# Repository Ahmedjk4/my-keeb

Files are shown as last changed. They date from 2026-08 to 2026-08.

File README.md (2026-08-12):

# my-keeb

A custom 60% mechanical keyboard that I designed from scratch, sponsored by Hack Club ❤️
### Each step is also found in commits with description

## Planning the Keyboard

I started by deciding on the layout and then decided what I wanted to include. I decided to include rgb leds, a rotary encoder, and a buzzer.
Took me about 15 minutes or less

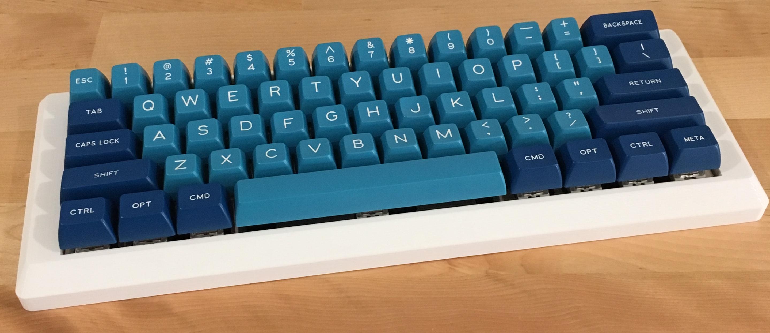
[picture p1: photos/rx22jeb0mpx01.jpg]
Planning


## Designing the PCB

I designed the schematic and PCB in KiCad. This was one of the hardest parts because it was my first time designing a PCB.
This holy step took more than 12 hours

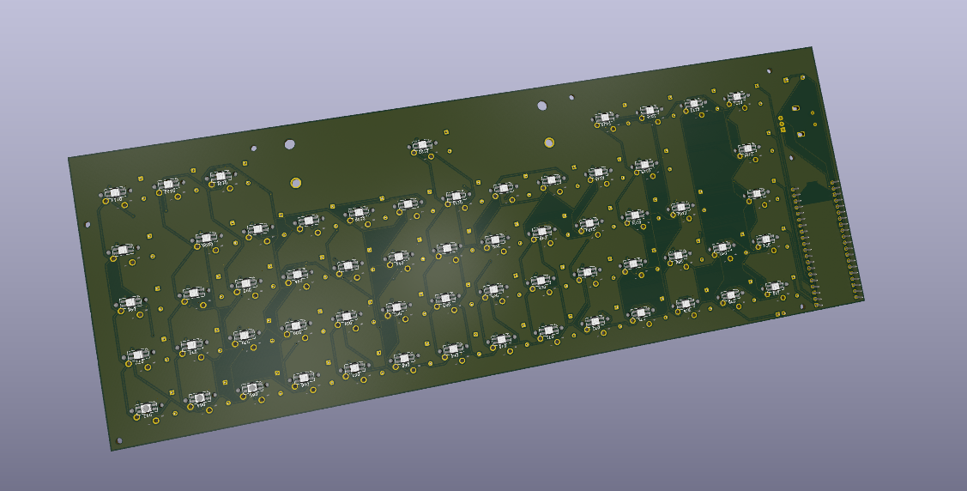
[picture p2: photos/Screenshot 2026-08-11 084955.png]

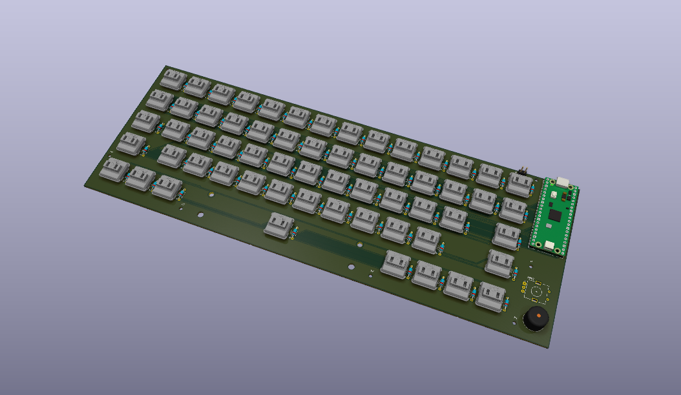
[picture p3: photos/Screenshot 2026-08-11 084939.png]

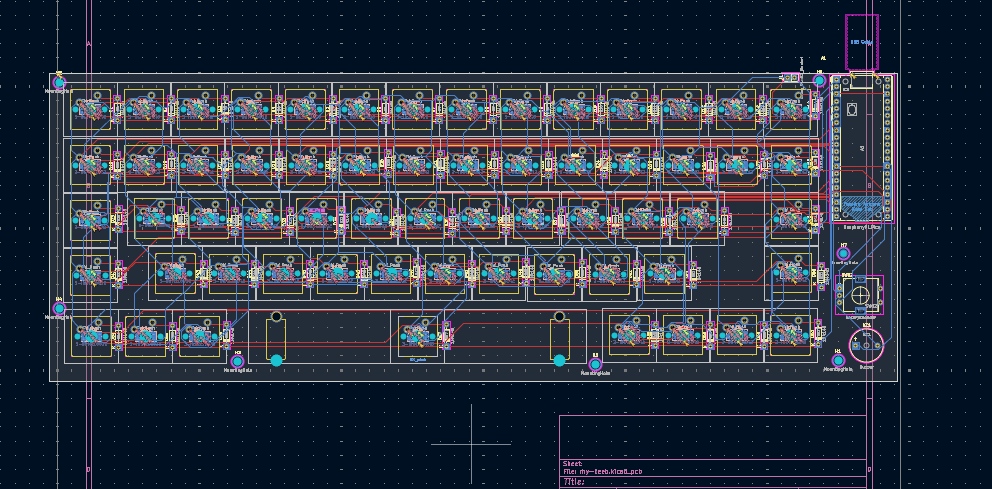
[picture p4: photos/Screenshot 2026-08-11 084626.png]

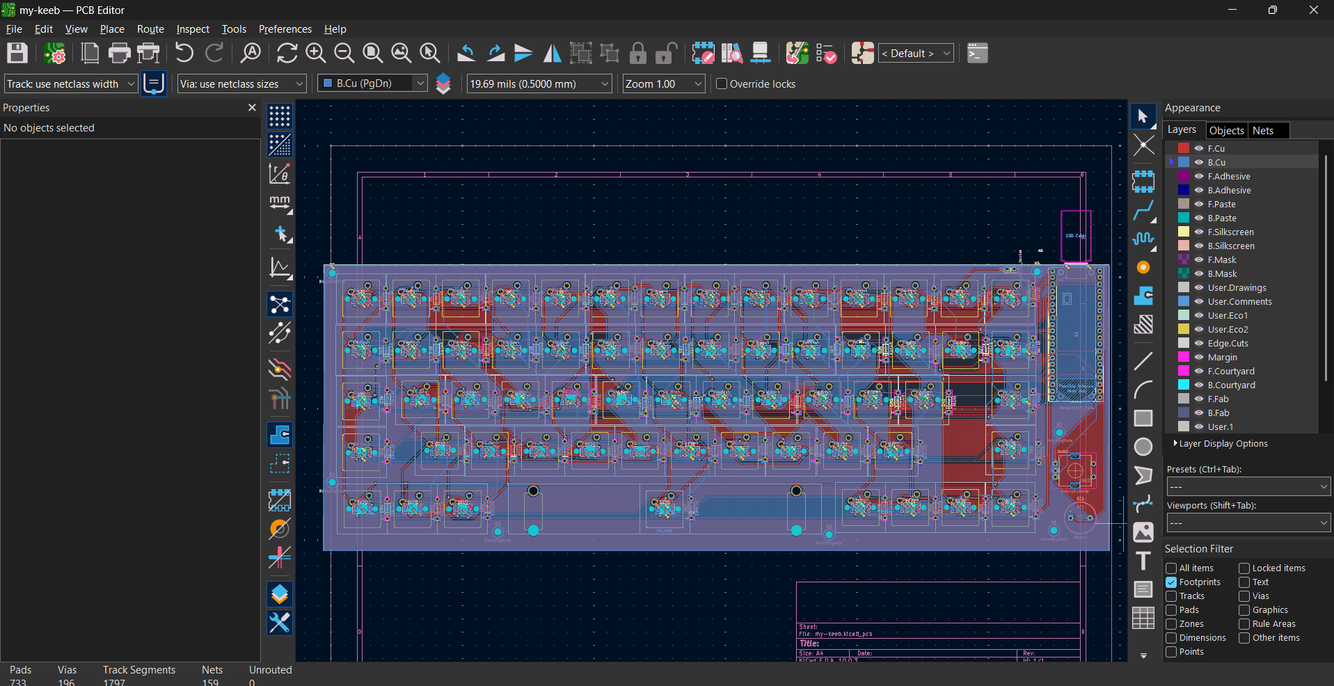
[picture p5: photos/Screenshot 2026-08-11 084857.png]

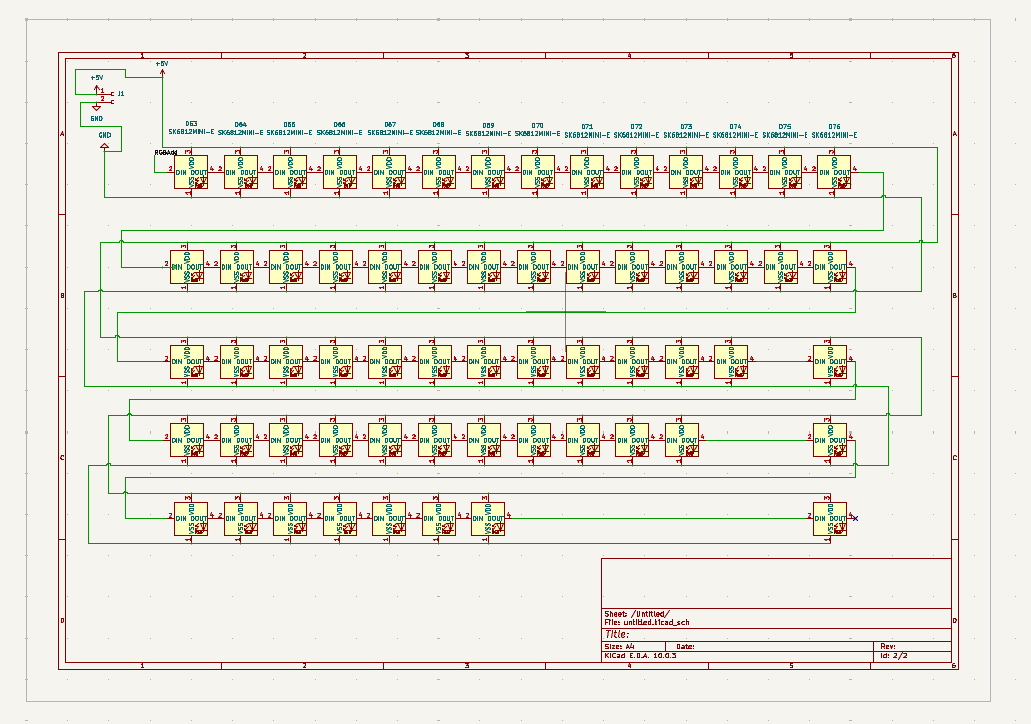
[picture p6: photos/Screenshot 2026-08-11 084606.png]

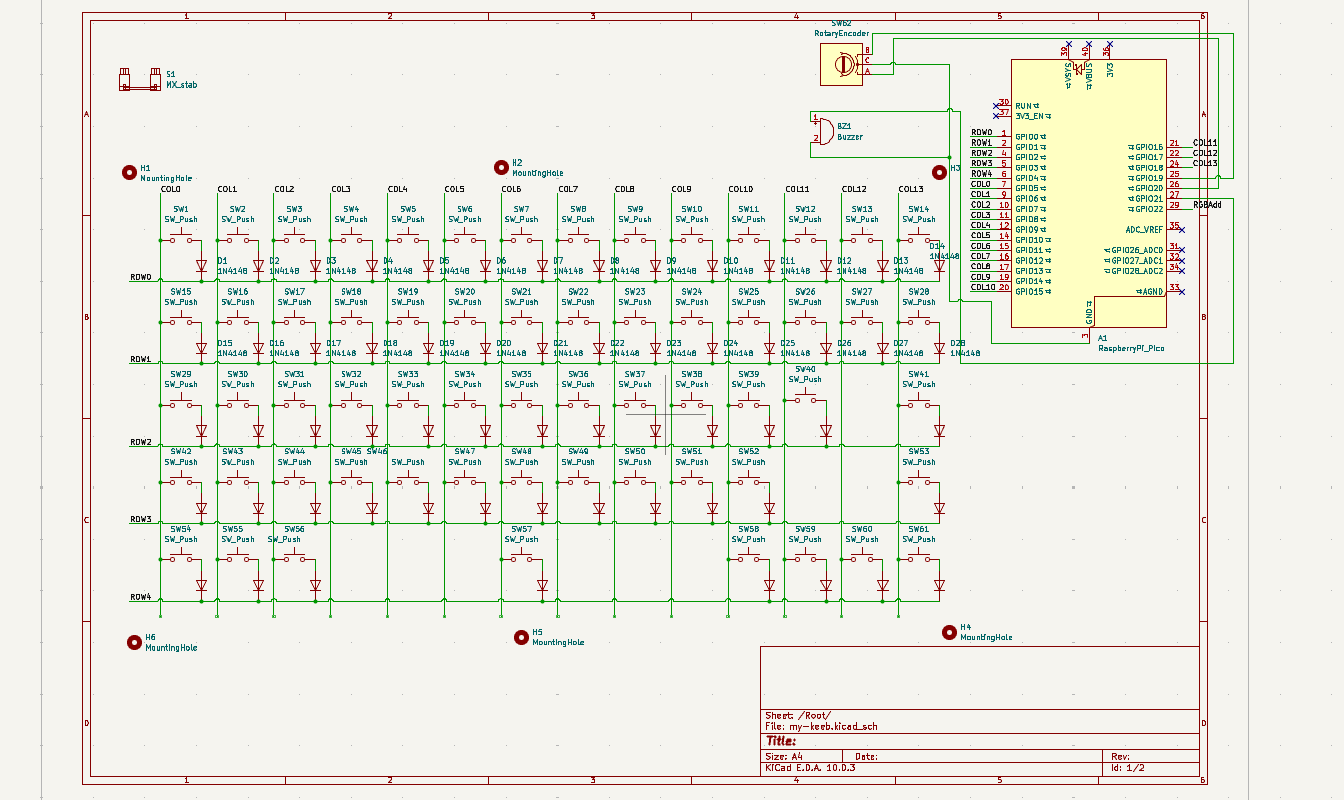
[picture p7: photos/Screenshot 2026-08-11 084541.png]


## Designing the Case

After finishing the PCB, I designed a 3D-printed case around it using Onshape.
Took me 6 hours because of the constrains tools always mess up when I try to move a sketch rectangle to fit the key.
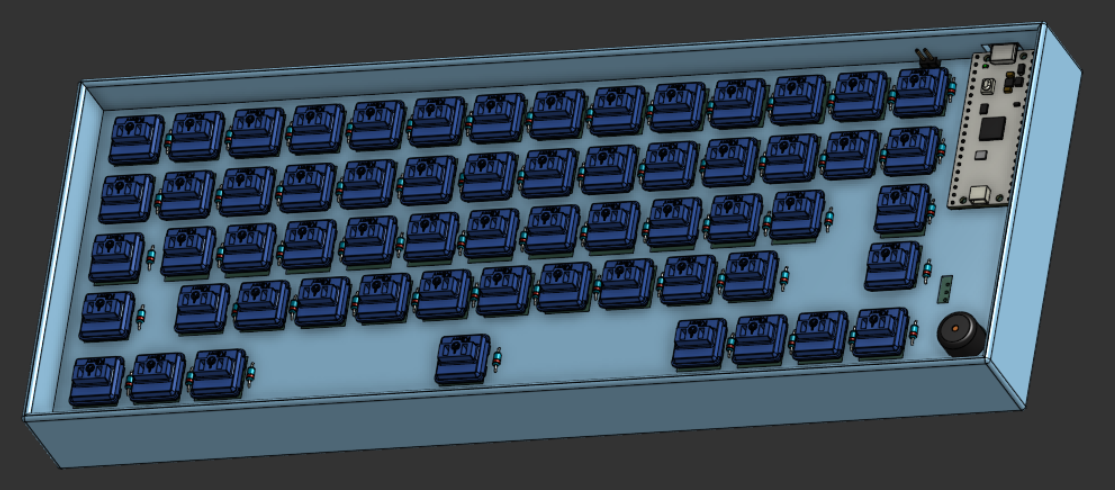
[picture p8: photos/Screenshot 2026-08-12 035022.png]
Case


## Writing the Firmware

Finally, I wrote the keyboard firmware using RMK firmware ( didn't write it I actually edited a .toml file ) and built it on github actions, on my repo https://github.com/Ahmedjk4/custom-keyboard-firmware/

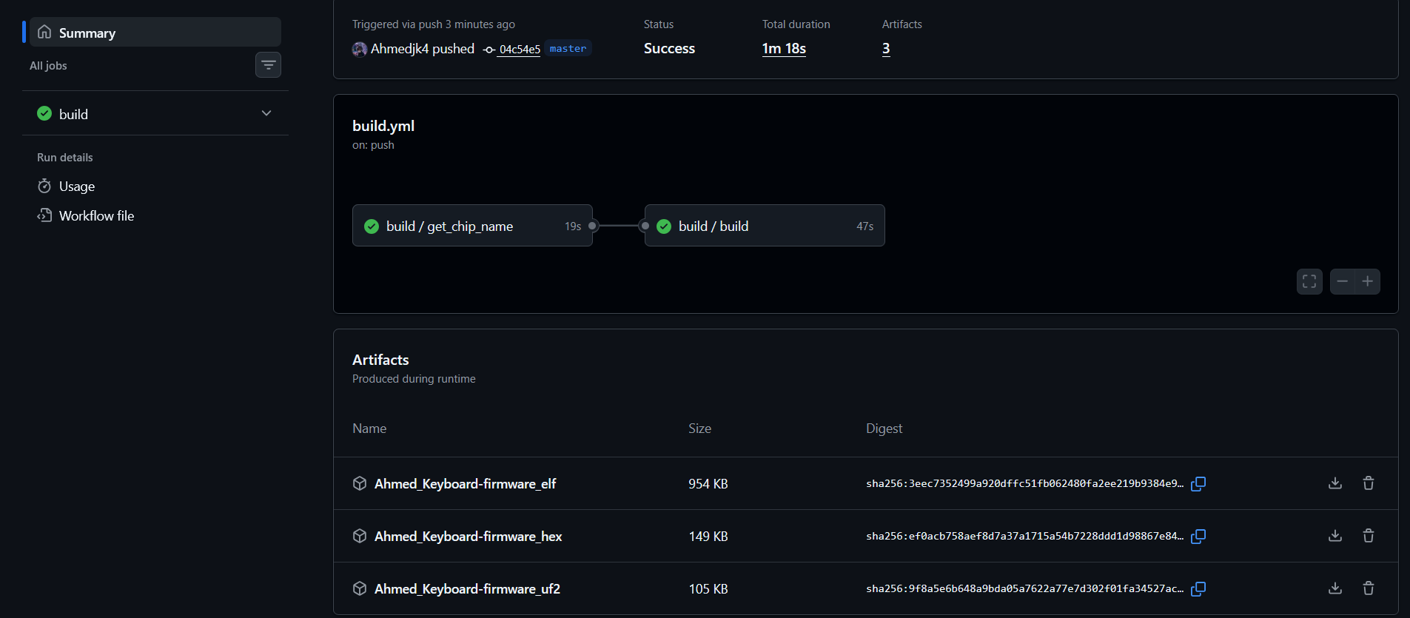
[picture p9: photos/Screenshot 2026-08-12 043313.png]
Firmware


## What I Learnt

I learnt a lot about PCB design, CAD, and embedded keyboard firmware.

Thanks to Hack Club for sponsoring the project! ❤️

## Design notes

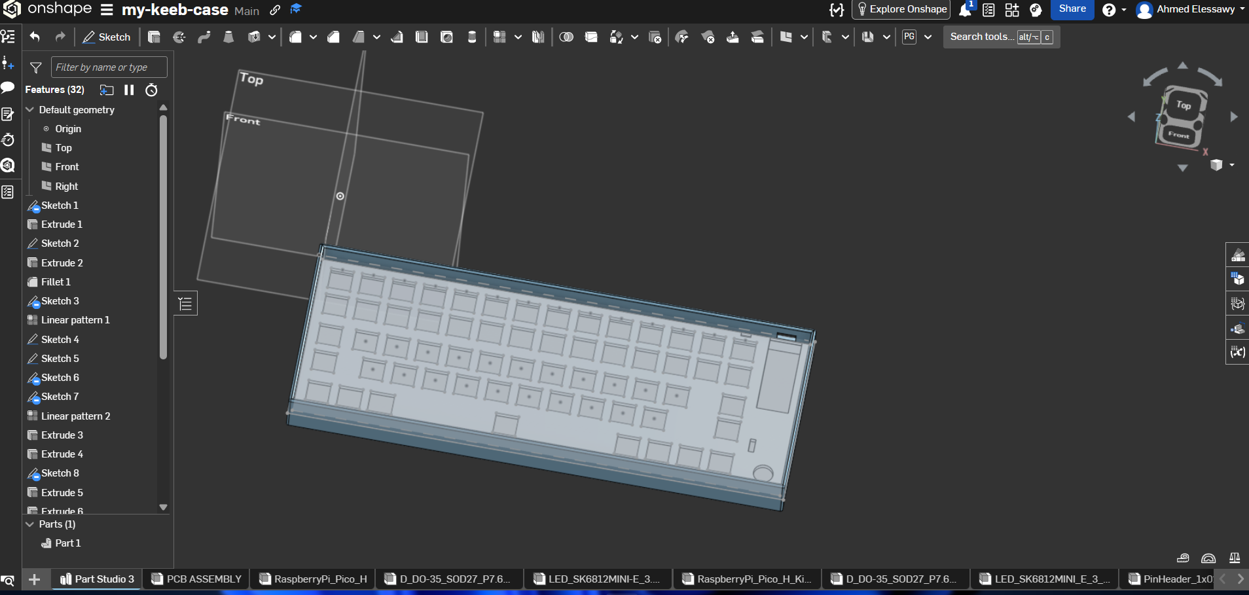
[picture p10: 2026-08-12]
photos/Screenshot 2026-08-12 035127.png

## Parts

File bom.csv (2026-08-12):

Item Name | Quantity | Price Per Unit In EGP | Price Per Unit In USD | Link | Total Cost In EGP | Total Cost In USD
Raspberry PI Pico (RP2040) | 1 | 375 pounds | 7.5$ | https://store.fut-electronics.com/products/raspberry-pi-model-b-mini-linux-arm-pc | 375 pounds | 7.5$
3 PCS Cyan Linear 40g Actuatuation 50M Keyboard Switch | 21 | 223 pounds | 4.4$ | https://www.amazon.eg/-/en/Mechanical-Actuation-Keystrokes-enthusiasts-construction/dp/B0GXSY4S7W | 4680 pounds | 93$
SK6812MINI-E 3228 SMD RGB LED | 61 | 10 pounds | 0.20$ | https://makerselectronics.com/product/sk6812mini-e-3228-smd-rgb-led-5v-similar-as-ws2812/ | 610 pounds | 12$
Diode 1n4007 | 61 | 0.5 pounds | 0.01$ | https://www.ram-e-shop.com/ar/shop/1n4148-1n4148-high-speed-fast-switching-diode-300ma-100v-dywd-sry-5636 | 30.5 pounds | 0.6$
k512 keycaps | 1 | 325 pounds | 7$ | https://www.noon.com/egypt-ar/k512-rgb-1-104-keys-replacement-keycaps-set-with-multimedia-keys-for-mechanical-keyboard-premium-black-pbt-keycaps-for-full-size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 | 325 pounds | 7$
EC11 rotary encoder | 1 | 25 pounds | 0.25$ | https://www.ram-e-shop.com/ar/shop/pot-ec11-rotary-5pin-20mm-ec11-rotary-encoder-with-push-button-switch-5pin-20mm-silver-9624 | 25 pounds | 0.25$
Buzzer 3v | 1 | 8.5 pounds | 0.17$ | https://www.ram-e-shop.com/ar/shop/buzzer3v-small-buzzer-3v-bzr-sfr-6124 | 8.5 pounds | 0.17$
J1 pin header | 1 | 1 pound | 0.02$ | https://makerselectronics.com/product/pin-headers-male-2-54mm-5pin-straight-black-11mm/ | 1 pound | 0.02$

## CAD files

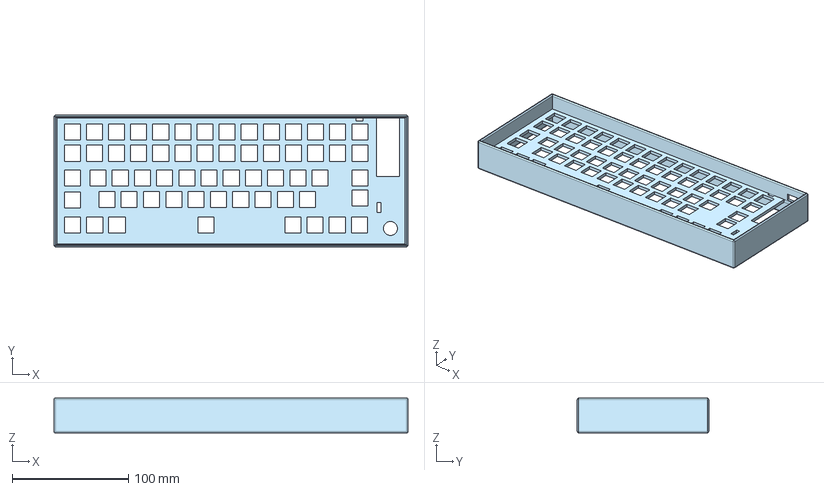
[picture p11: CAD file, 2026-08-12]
case/keeb case.step
304.6 x 113.2 x 30.0 mm

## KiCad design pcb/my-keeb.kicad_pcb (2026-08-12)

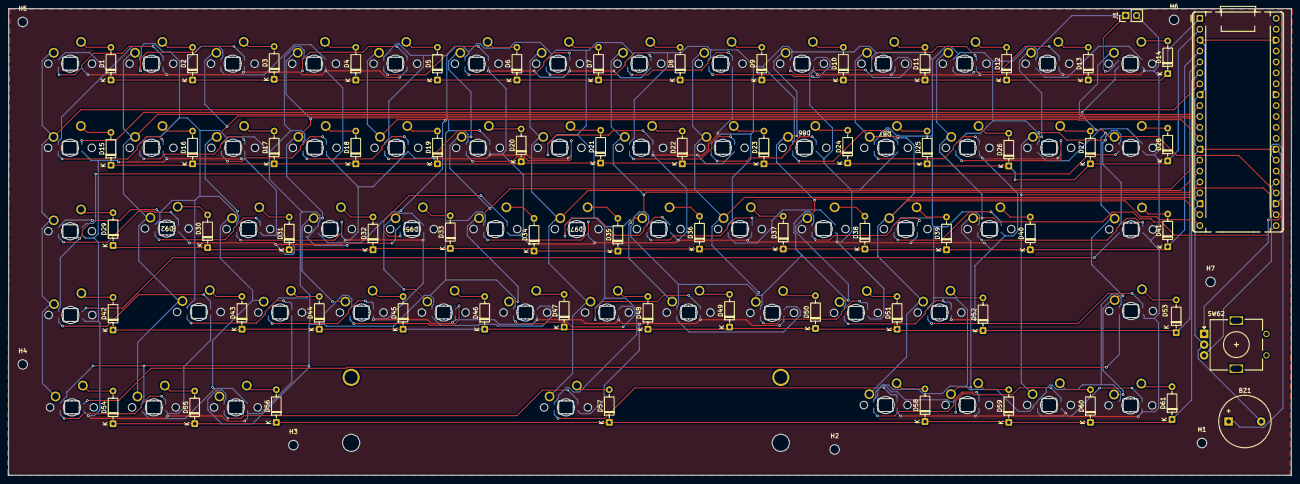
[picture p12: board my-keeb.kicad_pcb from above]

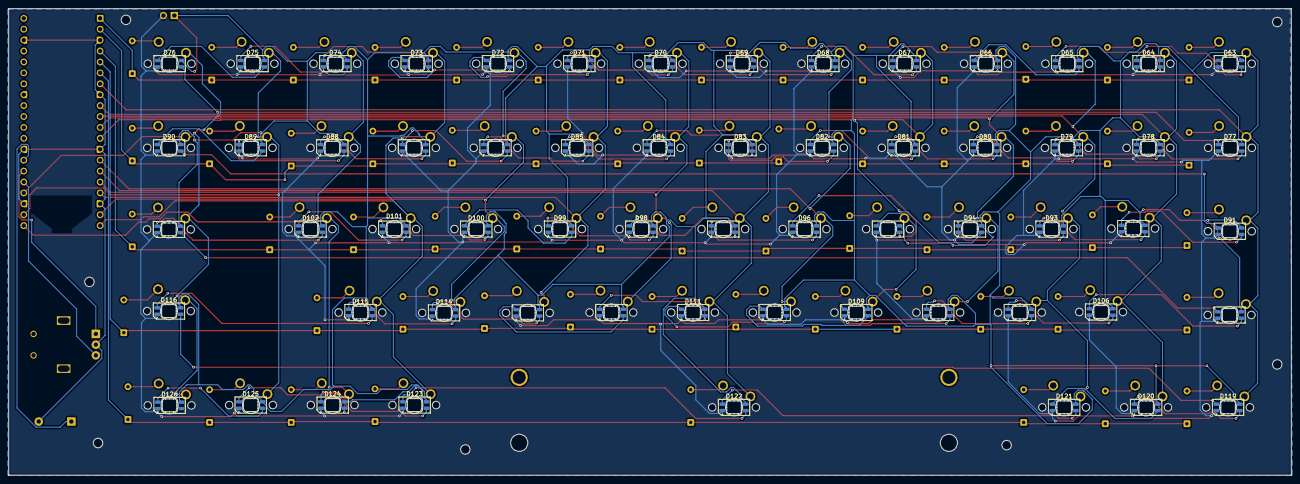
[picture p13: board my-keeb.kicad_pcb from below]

Board: 2 copper layers, 298.6 x 108.6 mm, 195 parts (61 on the bottom side), 146 nets.

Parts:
A1: RaspberryPi_Pico; RaspberryPi_Pico_Common_THT
BZ1: Buzzer; Buzzer_12x9.5RM7.6
D1, D2, D3, D4, D5, D6, D7, D8, D9, D10, D11, D12, D13, D14, D15, D16, D17, D18, D19, D20, D21, D22, D23, D24, D25, D26, D27, D28, D29, D30, D31, D32, D33, D34, D35, D36, D37, D38, D39, D40, D41, D42, D43, D44, D45, D46, D47, D48, D49, D50, D51, D52, D53, D54, D55, D56, D57, D58, D59, D60, D61: 1N4148; D_DO-35_SOD27_P7.62mm_Horizontal
D63, D64, D65, D66, D67, D68, D69, D70, D71, D72, D73, D74, D75, D76, D77, D78, D79, D80, D81, D82, D83, D84, D85, D86, D87, D88, D89, D90, D91, D92, D93, D94, D95, D96, D97, D98, D99, D100, D101, D102, D103, D105, D106, D107, D108, D109, D110, D111, D112, D113, D114, D115, D116, D119, D120, D121, D122, D123, D124, D125, D126: SK6812MINI-E; LED_SK6812MINI-E_3.2x2.8mm_P1.5mm_ReverseMount
H1, H2, H3, H4, H5, H6, H7: MountingHole; MountingHole_2.2mm_M2
J1: Conn_01x02_Socket; PinHeader_1x02_P2.54mm_Vertical
S1: MX_stab; STAB_MX_P_6.25u
SW1, SW2, SW3, SW4, SW5, SW6, SW7, SW8, SW9, SW10, SW11, SW12, SW13, SW14, SW15, SW16, SW17, SW18, SW19, SW20, SW21, SW22, SW23, SW24, SW25, SW26, SW27, SW28, SW29, SW30, SW31, SW32, SW33, SW34, SW35, SW36, SW37, SW38, SW39, SW40, SW41, SW42, SW43, SW44, SW45, SW46, SW47, SW48, SW49, SW50, SW51, SW52, SW53, SW54, SW55, SW56, SW57, SW58, SW59, SW60, SW61: SW_Push; SW_MX_1u
SW62: RotaryEncoder; RotaryEncoder_Alps_EC11E_Vertical_H20mm

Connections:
+5V: D63.3 (VDD), D64.3 (VDD), D65.3 (VDD), D66.3 (VDD), D67.3 (VDD), D68.3 (VDD), D69.3 (VDD), D70.3 (VDD), D71.3 (VDD), D72.3 (VDD), D73.3 (VDD), D74.3 (VDD), D75.3 (VDD), D76.3 (VDD), D77.3 (VDD), D78.3 (VDD), D79.3 (VDD), D80.3 (VDD), D81.3 (VDD), D82.3 (VDD), D83.3 (VDD), D84.3 (VDD), D85.3 (VDD), D86.3 (VDD), D87.3 (VDD), D88.3 (VDD), D89.3 (VDD), D90.3 (VDD), D91.3 (VDD), D92.3 (VDD), D93.3 (VDD), D94.3 (VDD), D95.3 (VDD), D96.3 (VDD), D97.3 (VDD), D98.3 (VDD), D99.3 (VDD), D100.3 (VDD), D101.3 (VDD), D102.3 (VDD), D103.3 (VDD), D105.3 (VDD), D106.3 (VDD), D107.3 (VDD), D108.3 (VDD), D109.3 (VDD), D110.3 (VDD), D111.3 (VDD), D112.3 (VDD), D113.3 (VDD), D114.3 (VDD), D115.3 (VDD), D116.3 (VDD), D119.3 (VDD), D120.3 (VDD), D121.3 (VDD), D122.3 (VDD), D123.3 (VDD), D124.3 (VDD), D125.3 (VDD), D126.3 (VDD), J1.1
/Root/COL0: A1.7 (GPIO5), SW1.1, SW15.1, SW29.1, SW42.1, SW54.1
/Root/COL1: A1.9 (GPIO6), SW2.1, SW16.1, SW30.1, SW43.1, SW55.1
/Root/COL2: A1.10 (GPIO7), SW3.1, SW17.1, SW31.1, SW44.1, SW56.1
/Root/COL3: A1.11 (GPIO8), SW4.1, SW18.1, SW32.1, SW45.1
/Root/COL4: A1.12 (GPIO9), SW5.1, SW19.1, SW33.1, SW46.1
/Root/COL5: A1.14 (GPIO10), SW6.1, SW20.1, SW34.1, SW47.1
/Root/COL6: A1.15 (GPIO11), SW7.1, SW21.1, SW35.1, SW48.1, SW57.1
/Root/COL7: A1.16 (GPIO12), SW8.1, SW22.1, SW36.1, SW49.1
/Root/COL8: A1.17 (GPIO13), SW9.1, SW23.1, SW37.1, SW50.1
/Root/COL9: A1.19 (GPIO14), SW10.1, SW24.1, SW38.1, SW51.1
/Root/COL10: A1.20 (GPIO15), SW11.1, SW25.1, SW39.1, SW52.1, SW58.1
/Root/COL11: A1.21 (GPIO16), SW12.1, SW26.1, SW40.1, SW59.1
/Root/COL12: A1.22 (GPIO17), SW13.1, SW27.1, SW60.1
/Root/COL13: A1.24 (GPIO18), SW14.1, SW28.1, SW41.1, SW53.1, SW61.1
/Root/ROW0: A1.1 (GPIO0), D1.1 (K), D2.1 (K), D3.1 (K), D4.1 (K), D5.1 (K), D6.1 (K), D7.1 (K), D8.1 (K), D9.1 (K), D10.1 (K), D11.1 (K), D12.1 (K), D13.1 (K), D14.1 (K)
/Root/ROW1: A1.2 (GPIO1), D15.1 (K), D16.1 (K), D17.1 (K), D18.1 (K), D19.1 (K), D20.1 (K), D21.1 (K), D22.1 (K), D23.1 (K), D24.1 (K), D25.1 (K), D26.1 (K), D27.1 (K), D28.1 (K)
/Root/ROW2: A1.4 (GPIO2), D29.1 (K), D30.1 (K), D31.1 (K), D32.1 (K), D33.1 (K), D34.1 (K), D35.1 (K), D36.1 (K), D37.1 (K), D38.1 (K), D39.1 (K), D40.1 (K), D41.1 (K)
/Root/ROW3: A1.5 (GPIO3), D42.1 (K), D43.1 (K), D44.1 (K), D45.1 (K), D46.1 (K), D47.1 (K), D48.1 (K), D49.1 (K), D50.1 (K), D51.1 (K), D52.1 (K), D53.1 (K)
/Root/ROW4: A1.6 (GPIO4), D54.1 (K), D55.1 (K), D56.1 (K), D57.1 (K), D58.1 (K), D59.1 (K), D60.1 (K), D61.1 (K)
GND: D63.1 (VSS), D64.1 (VSS), D65.1 (VSS), D66.1 (VSS), D67.1 (VSS), D68.1 (VSS), D69.1 (VSS), D70.1 (VSS), D71.1 (VSS), D72.1 (VSS), D73.1 (VSS), D74.1 (VSS), D75.1 (VSS), D76.1 (VSS), D77.1 (VSS), D78.1 (VSS), D79.1 (VSS), D80.1 (VSS), D81.1 (VSS), D82.1 (VSS), D83.1 (VSS), D84.1 (VSS), D85.1 (VSS), D86.1 (VSS), D87.1 (VSS), D88.1 (VSS), D89.1 (VSS), D90.1 (VSS), D91.1 (VSS), D92.1 (VSS), D93.1 (VSS), D94.1 (VSS), D95.1 (VSS), D96.1 (VSS), D97.1 (VSS), D98.1 (VSS), D99.1 (VSS), D100.1 (VSS), D101.1 (VSS), D102.1 (VSS), D103.1 (VSS), D105.1 (VSS), D106.1 (VSS), D107.1 (VSS), D108.1 (VSS), D109.1 (VSS), D110.1 (VSS), D111.1 (VSS), D112.1 (VSS), D113.1 (VSS), D114.1 (VSS), D115.1 (VSS), D116.1 (VSS), D119.1 (VSS), D120.1 (VSS), D121.1 (VSS), D122.1 (VSS), D123.1 (VSS), D124.1 (VSS), D125.1 (VSS), D126.1 (VSS), J1.2
unnamed: A1.25 (GPIO19), SW62.B
unnamed: A1.26 (GPIO20), SW62.A
unnamed: A1.27 (GPIO21), BZ1.1 (+)
unnamed: A1.3 (GND), A1.8 (GND), A1.13 (GND), A1.18 (GND), A1.23 (GND), A1.28 (GND), A1.38 (GND), BZ1.2 (-), SW62.C
unnamed: D1.2 (A), SW1.2
unnamed: D2.2 (A), SW2.2
unnamed: D3.2 (A), SW3.2
unnamed: D4.2 (A), SW4.2
unnamed: D5.2 (A), SW5.2
unnamed: D6.2 (A), SW6.2
unnamed: D7.2 (A), SW7.2
unnamed: D8.2 (A), SW8.2
unnamed: D9.2 (A), SW9.2
unnamed: D10.2 (A), SW10.2
unnamed: D11.2 (A), SW11.2
unnamed: D12.2 (A), SW12.2
unnamed: D13.2 (A), SW13.2
unnamed: D14.2 (A), SW14.2
unnamed: D15.2 (A), SW15.2
unnamed: D16.2 (A), SW16.2
unnamed: D17.2 (A), SW17.2
unnamed: D18.2 (A), SW18.2
unnamed: D19.2 (A), SW19.2
unnamed: D20.2 (A), SW20.2
unnamed: D21.2 (A), SW21.2
unnamed: D22.2 (A), SW22.2
unnamed: D23.2 (A), SW23.2
unnamed: D24.2 (A), SW24.2
unnamed: D25.2 (A), SW25.2
unnamed: D26.2 (A), SW26.2
unnamed: D27.2 (A), SW27.2
unnamed: D28.2 (A), SW28.2
unnamed: D29.2 (A), SW29.2
unnamed: D30.2 (A), SW30.2
unnamed: D31.2 (A), SW31.2
unnamed: D32.2 (A), SW32.2
unnamed: D33.2 (A), SW33.2
unnamed: D34.2 (A), SW34.2
unnamed: D35.2 (A), SW35.2
unnamed: D36.2 (A), SW36.2
unnamed: D37.2 (A), SW37.2
unnamed: D38.2 (A), SW38.2
unnamed: D39.2 (A), SW39.2
unnamed: D40.2 (A), SW40.2
unnamed: D41.2 (A), SW41.2
unnamed: D42.2 (A), SW42.2
unnamed: D43.2 (A), SW43.2
unnamed: D44.2 (A), SW44.2
unnamed: D45.2 (A), SW45.2
unnamed: D46.2 (A), SW46.2
unnamed: D47.2 (A), SW47.2
unnamed: D48.2 (A), SW48.2
unnamed: D49.2 (A), SW49.2
unnamed: D50.2 (A), SW50.2
unnamed: D51.2 (A), SW51.2
unnamed: D52.2 (A), SW52.2
unnamed: D53.2 (A), SW53.2
unnamed: D54.2 (A), SW54.2
unnamed: D55.2 (A), SW55.2
unnamed: D56.2 (A), SW56.2
unnamed: D57.2 (A), SW57.2
unnamed: D58.2 (A), SW58.2
unnamed: D59.2 (A), SW59.2
unnamed: D60.2 (A), SW60.2
unnamed: D61.2 (A), SW61.2
unnamed: D63.4 (DOUT), D64.2 (DIN)
unnamed: D64.4 (DOUT), D65.2 (DIN)
unnamed: D65.4 (DOUT), D66.2 (DIN)
unnamed: D66.4 (DOUT), D67.2 (DIN)
unnamed: D67.4 (DOUT), D68.2 (DIN)
unnamed: D68.4 (DOUT), D69.2 (DIN)
unnamed: D69.4 (DOUT), D70.2 (DIN)
unnamed: D70.4 (DOUT), D71.2 (DIN)
unnamed: D71.4 (DOUT), D72.2 (DIN)
unnamed: D72.4 (DOUT), D73.2 (DIN)
unnamed: D73.4 (DOUT), D74.2 (DIN)
unnamed: D74.4 (DOUT), D75.2 (DIN)
unnamed: D75.4 (DOUT), D76.2 (DIN)
unnamed: D76.4 (DOUT), D77.2 (DIN)
unnamed: D77.4 (DOUT), D78.2 (DIN)
unnamed: D78.4 (DOUT), D79.2 (DIN)
unnamed: D79.4 (DOUT), D80.2 (DIN)
unnamed: D80.4 (DOUT), D81.2 (DIN)
unnamed: D81.4 (DOUT), D82.2 (DIN)
unnamed: D82.4 (DOUT), D83.2 (DIN)
unnamed: D83.4 (DOUT), D84.2 (DIN)
unnamed: D84.4 (DOUT), D85.2 (DIN)
unnamed: D85.4 (DOUT), D86.2 (DIN)
unnamed: D86.4 (DOUT), D87.2 (DIN)
unnamed: D87.4 (DOUT), D88.2 (DIN)
unnamed: D88.4 (DOUT), D89.2 (DIN)
unnamed: D89.4 (DOUT), D90.2 (DIN)
unnamed: D90.4 (DOUT), D91.2 (DIN)
unnamed: D91.4 (DOUT), D92.2 (DIN)
unnamed: D92.4 (DOUT), D93.2 (DIN)
unnamed: D93.4 (DOUT), D94.2 (DIN)
unnamed: D94.4 (DOUT), D95.2 (DIN)
unnamed: D95.4 (DOUT), D96.2 (DIN)
unnamed: D96.4 (DOUT), D97.2 (DIN)
unnamed: D97.4 (DOUT), D98.2 (DIN)
unnamed: D98.4 (DOUT), D99.2 (DIN)
unnamed: D99.4 (DOUT), D100.2 (DIN)
unnamed: D100.4 (DOUT), D101.2 (DIN)
unnamed: D101.4 (DOUT), D102.2 (DIN)
unnamed: D102.4 (DOUT), D103.2 (DIN)
unnamed: D103.4 (DOUT), D105.2 (DIN)
unnamed: D105.4 (DOUT), D106.2 (DIN)
unnamed: D106.4 (DOUT), D107.2 (DIN)
unnamed: D107.4 (DOUT), D108.2 (DIN)
unnamed: D108.4 (DOUT), D109.2 (DIN)
unnamed: D109.4 (DOUT), D110.2 (DIN)
unnamed: D110.4 (DOUT), D111.2 (DIN)
unnamed: D111.4 (DOUT), D112.2 (DIN)
unnamed: D112.4 (DOUT), D113.2 (DIN)
unnamed: D113.4 (DOUT), D114.2 (DIN)
unnamed: D114.4 (DOUT), D115.2 (DIN)
unnamed: D115.4 (DOUT), D116.2 (DIN)
unnamed: D116.4 (DOUT), D119.2 (DIN)
unnamed: D119.4 (DOUT), D120.2 (DIN)
unnamed: D120.4 (DOUT), D121.2 (DIN)
unnamed: D121.4 (DOUT), D122.2 (DIN)
unnamed: D122.4 (DOUT), D123.2 (DIN)
unnamed: D123.4 (DOUT), D124.2 (DIN)
unnamed: D124.4 (DOUT), D125.2 (DIN)
unnamed: D125.4 (DOUT), D126.2 (DIN)

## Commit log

2026-08-10 Planning my keyboard Step
    I plan to make a keyboard as the one shown in this photo, and thinking of addijng a rotary encoder, oled screen and a buzzer for some sound effect XD
    I want the raspberry pi pico to be placed top left and the usb port facing upward, near the backspace and +/= key
    This step didn't take me 5 minutes
2026-08-11 Finished Designing The PCB Step ( hopefully )
    After more than 12 hours of hard work trying to figure out how does kicad work, I finally pulled it and had my schematic with the 2 sheets, the pcb arranged and routed ( was very hard istg ), and add 3d models to the keys and pico and the buzzer, the keys ones aren't so good ngl.
2026-08-12 Finished desinging the case step
    After 6 hours of God's CAD work, I can say it's done.
    Designed the case for the pcb, opened places for each switch, the pico, buzzer and enocder, and J1 connector
    here: https://cad.onshape.com/documents/ac0d0c8a76d47f62a8847ed2/w/3e72c33e2d57221932c06f57/e/e20cd8668801a9152e116827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
2026-08-12 create folder pcb
2026-08-12 upload pcb files
    [my-keeb.kicad_pcb, my-keeb.kicad_sch]
2026-08-12 upload step case 3d model from onshape
    [keeb case.step]
2026-08-12 upload bom.csv
    [bom.csv]
2026-10-17 Add Onshape model link to JOURNAL.md
    Added a link to the Onshape model for the keyboard case.
